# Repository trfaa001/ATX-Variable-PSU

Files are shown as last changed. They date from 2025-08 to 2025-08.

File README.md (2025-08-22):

# ATX-Variable-PSU
DIY variable power supply using an ATX PSU and buck converter.

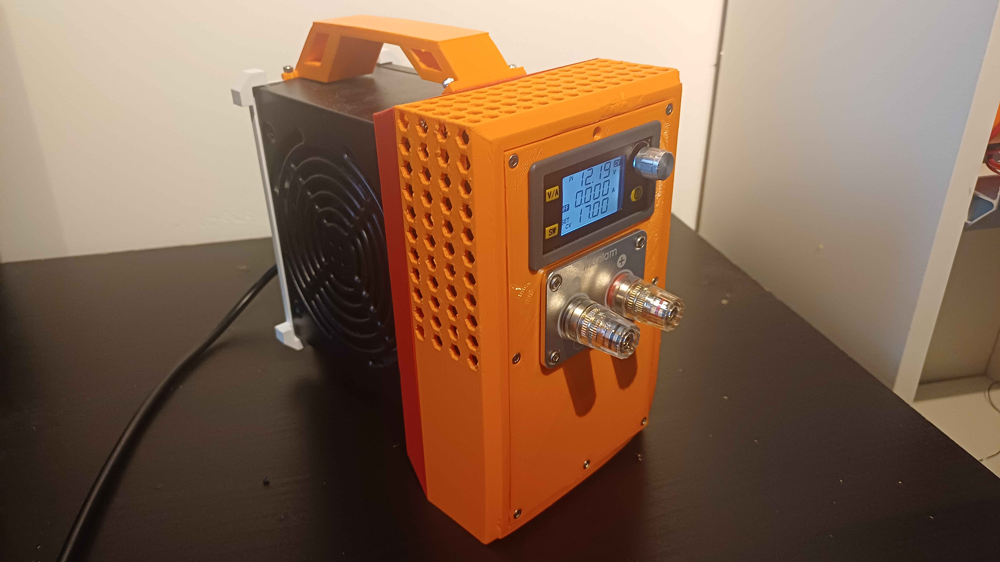
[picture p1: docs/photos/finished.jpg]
Project Image


## Features
---

* Voltage: 0-50V
* Amperage: 8A
* Repurposing ATX PSU
* Low-cost

## Parts list
---
| Qty | Component | Notes | Link |
|-----|---|---|---|
| 1 | ATX Power Supply | Corsair CV650 | [Product page](https://www.corsair.com/us/en/p/psu/cp-9020211-na/cv-series-cv650-650-watt-80-plus-bronze-certified-psu-cp-9020211-na) |
| 1 | Buck Converter Module | XY5008E from Aliexpress | [Product page](https://www.aliexpress.com/item/1005005247897362.html) |
| 1 | Banana Plug Connectors | 1 red, 1 black | [Product page](https://www.aliexpress.com/item/1005006516519813.html) |
| 1 | XT90 Female Connector | High current output connector | [Product page](https://www.aliexpress.com/item/1005007620266465.html) |
| 1 | XT90 Male Plug | High current plug | [Product page](https://www.aliexpress.com/item/1005008308472728.html) |
| 1 | 4mm Banana plug to alligator clip | Standard test leads | [Product page](https://www.aliexpress.com/item/1005006537881871.html) |
| 1 | Enclosure | 3D printed (see Fusion file) | [Mechanical (Fusion 360 + STL)](mechanical/) |
| 1 | PCB | Connecting the ATX 12V to a single line | [PCB design (Kicad + exports)](hardware/kicad/) |
| ~30 | Screws M3x10 mm | Connecting the parts togheter | [Product page](https://www.aliexpress.com/item/32836902463.html) |
| — | Wires, Heat Shrink, etc. | For connections | — |

## Recommended 3d print settings
---
| Setting | Value | Notes |
|---|---|---|
| Layer Height | maximum 0.22 mm | Standard balance of speed/quality |
| Infill | minimum 10% | Higher infill for more strength |
| Perimeters | 2-3 | Improves wall strength |
| Material | PLA or PETG | PETG for heat resistance |
| Supports | everywhere | Depends on model orientation |
| Bed Adhesion | Brim | If warping occurs |

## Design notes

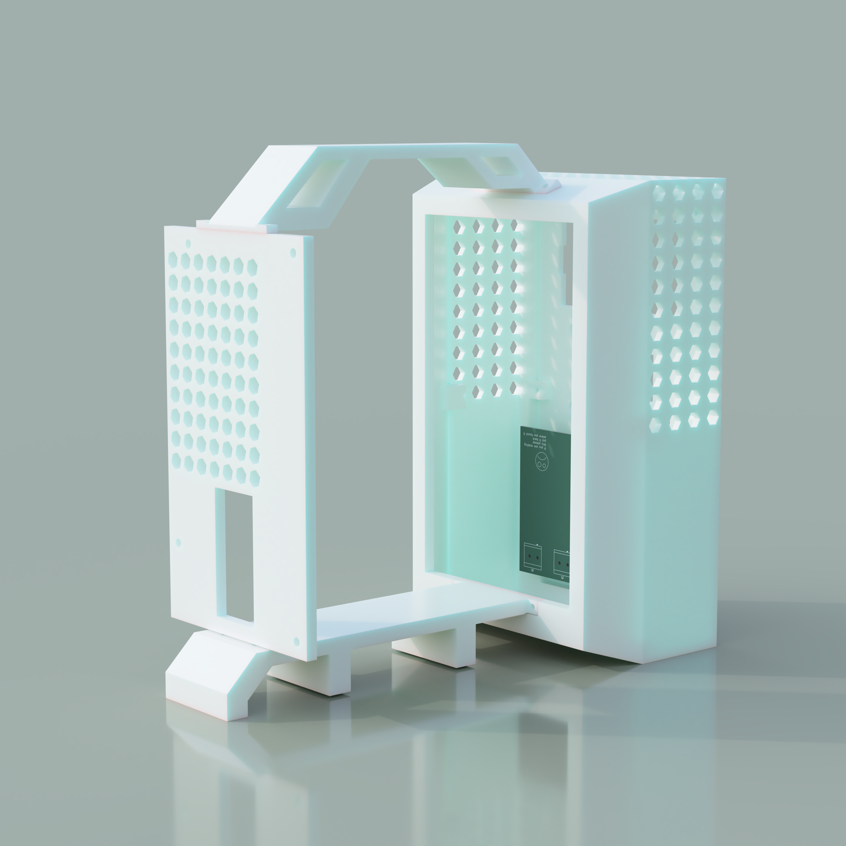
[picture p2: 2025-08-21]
mechanical/photos/Variable PSU back.png

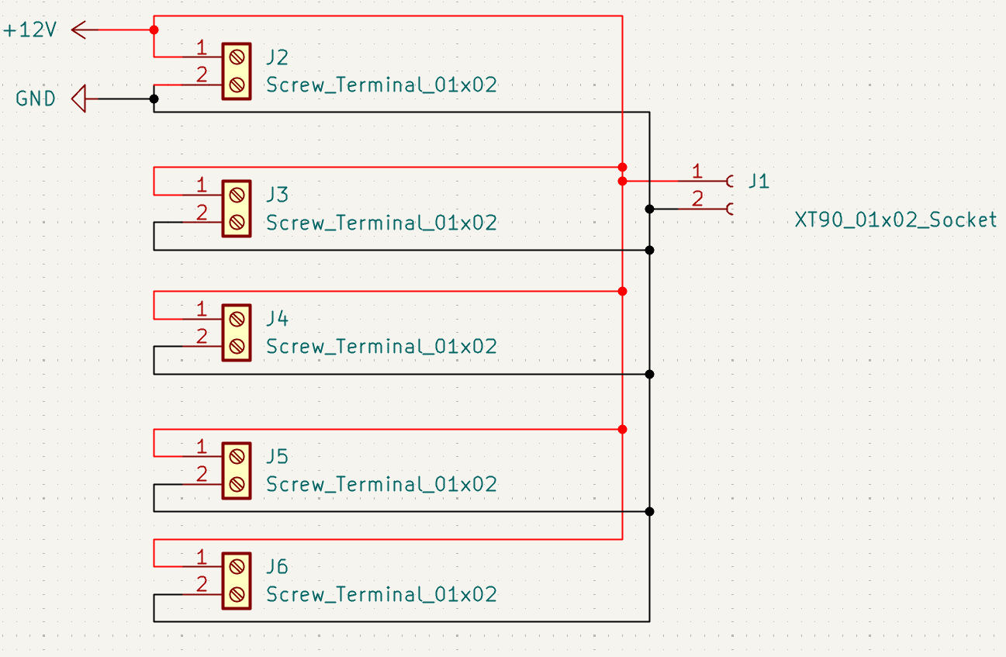
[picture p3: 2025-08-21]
hardware/kicad/photos/schematic.png

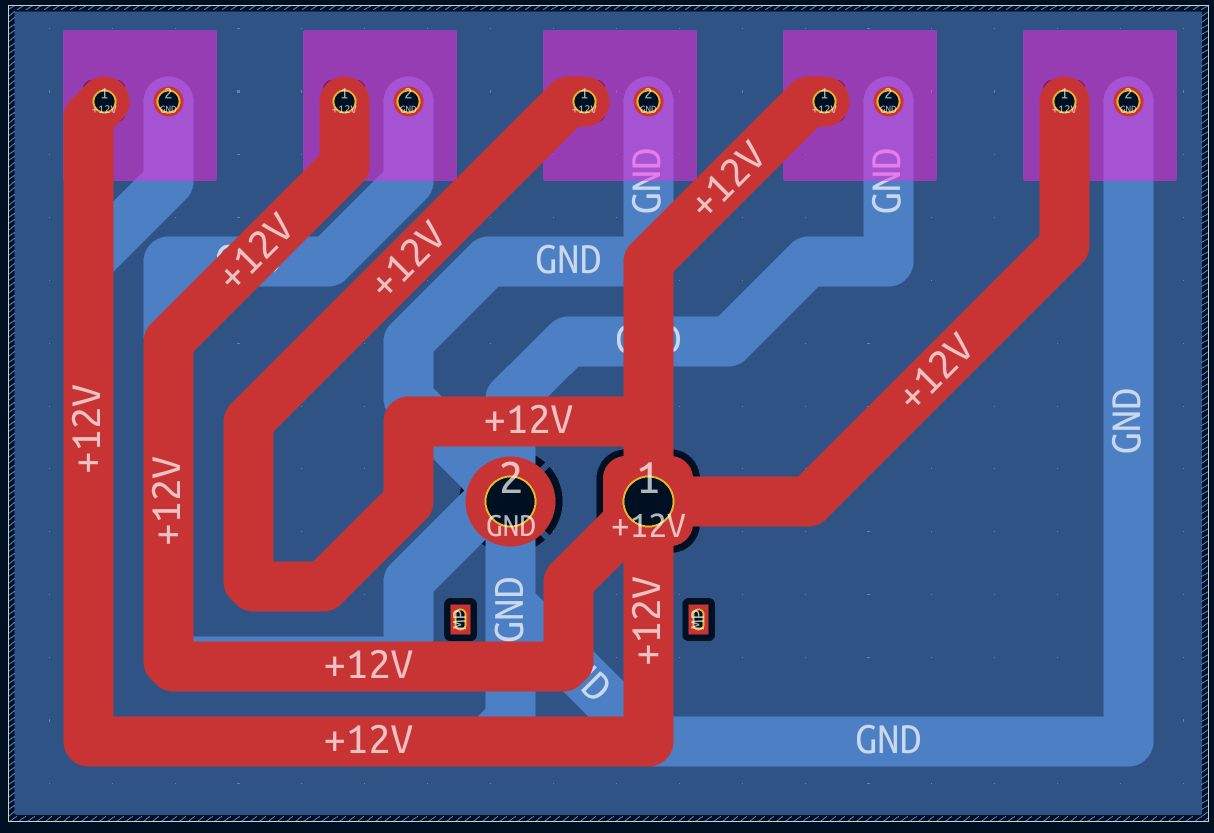
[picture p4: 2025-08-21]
hardware/kicad/photos/pcb.png

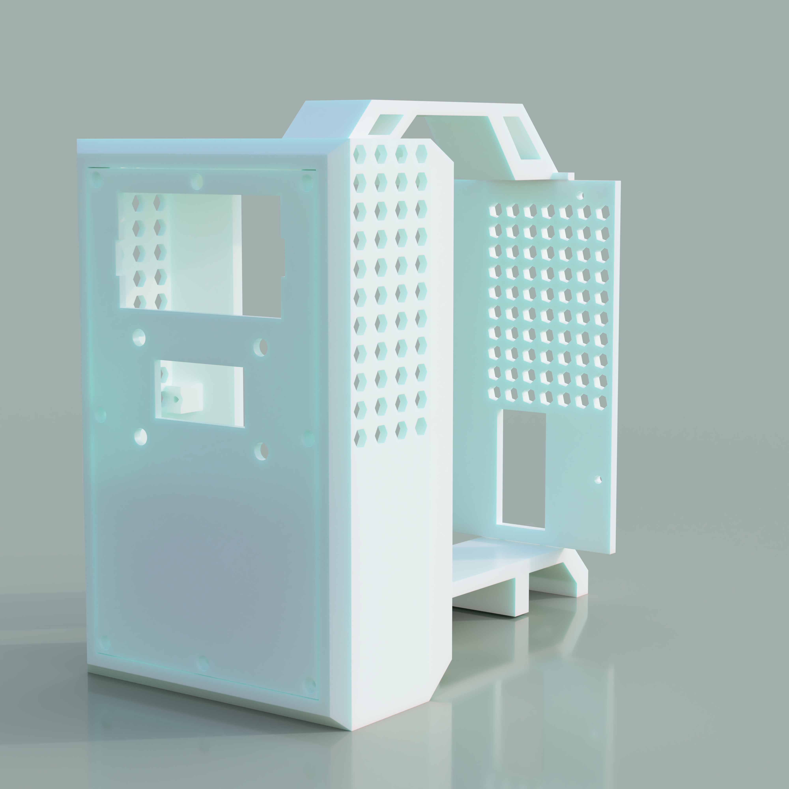
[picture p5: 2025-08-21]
mechanical/photos/Variable PSU front.png

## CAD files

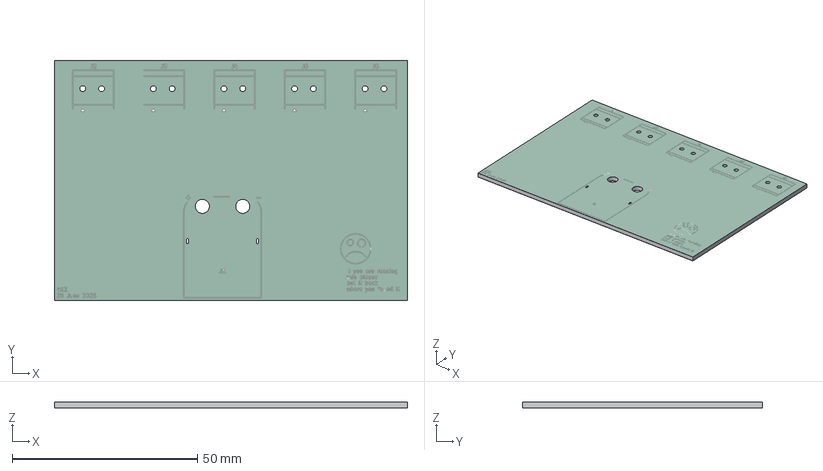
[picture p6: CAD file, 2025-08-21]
hardware/kicad/exports/PSU to buck.step
95.2 x 64.8 x 1.66 mm
PSU to buck_silkscreen
PSU to buck_soldermask
PSU to buck_PCB

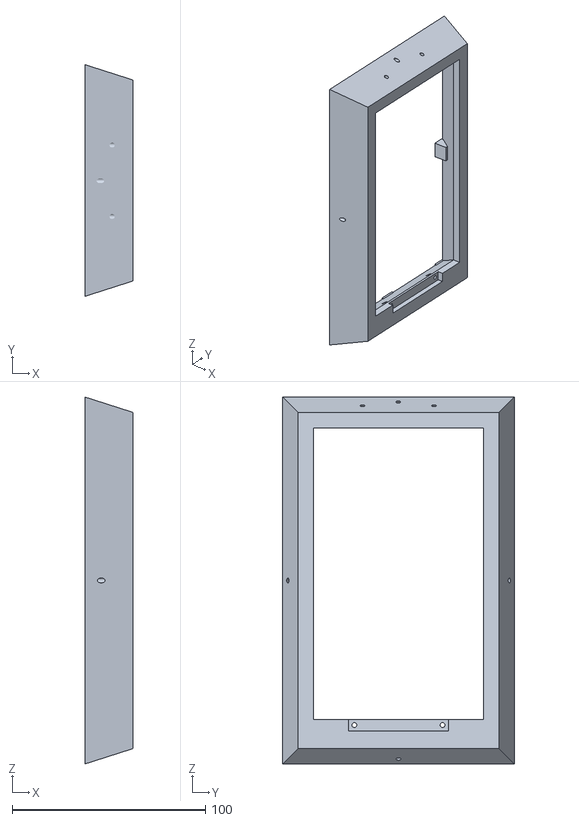
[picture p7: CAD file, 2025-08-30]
mechanical/3D print STLs/Back.stl
25.0 x 120.0 x 190.0

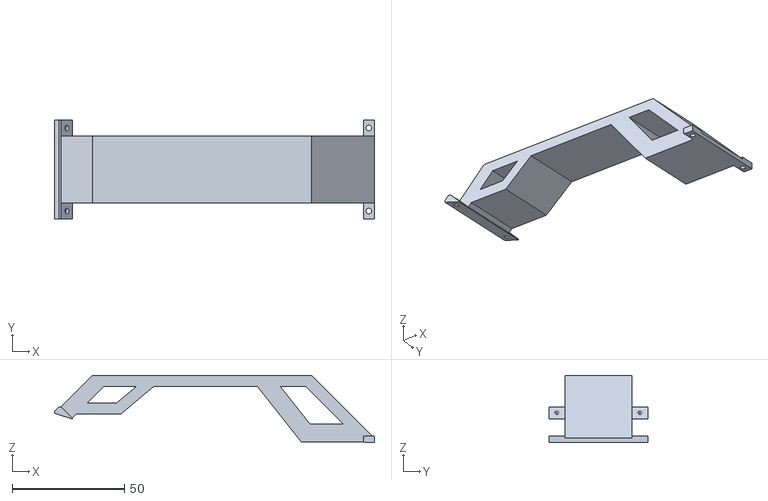
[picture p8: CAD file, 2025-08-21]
mechanical/3D print STLs/Handle.stl
142.5 x 44.0 x 30.0

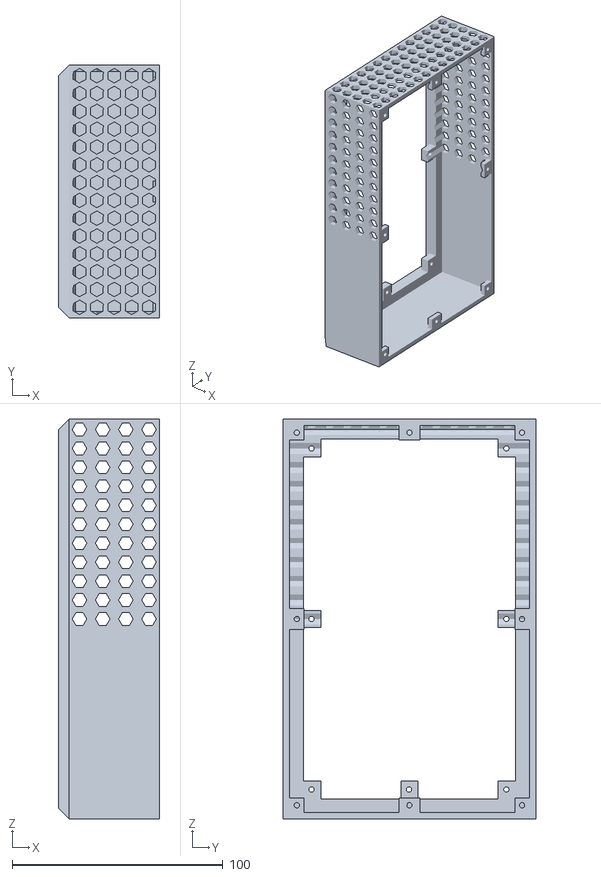
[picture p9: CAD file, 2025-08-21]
mechanical/3D print STLs/Front.stl
48.0 x 120.0 x 190.0

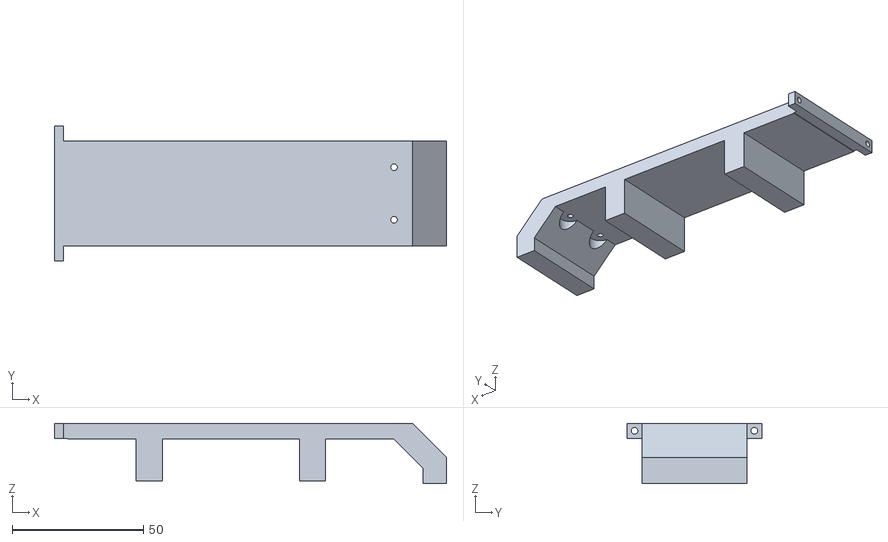
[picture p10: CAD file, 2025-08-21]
mechanical/3D print STLs/Bottom.stl
149.5 x 51.4 x 23.0

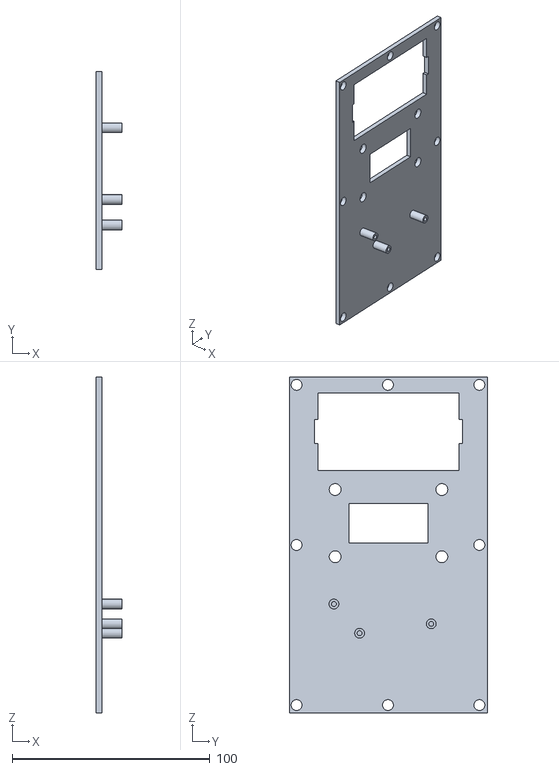
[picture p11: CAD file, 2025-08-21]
mechanical/3D print STLs/FrontPlate.stl
13.0 x 100.0 x 170.0

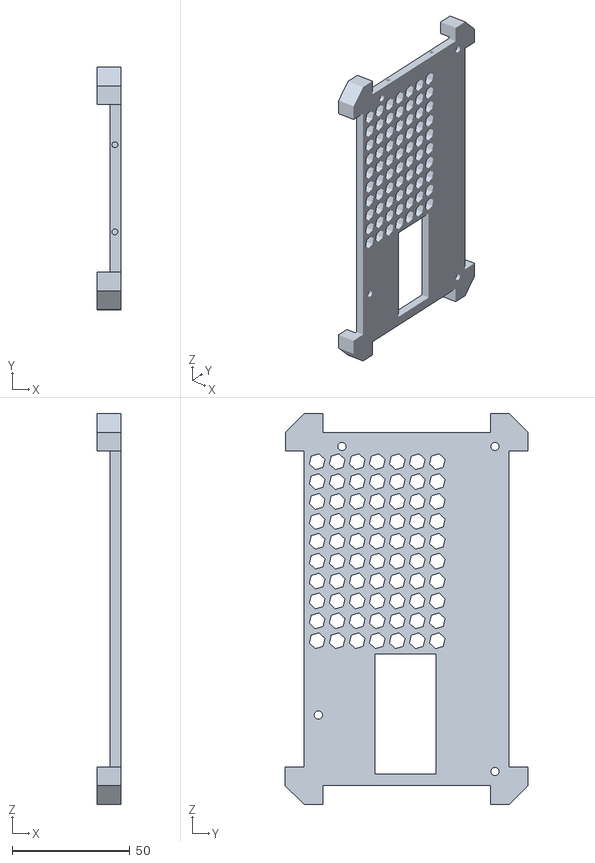
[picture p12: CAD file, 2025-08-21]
mechanical/3D print STLs/Backplate.stl
10.0 x 103.1 x 166.0

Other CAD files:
mechanical/Blender/assets/materials/geometric-patter_19b2c3d9-954c-4562-87f0-849a1d0f68e2/geometric-pattern-black-plastic_2K_b37b10a6-8506-4bd7-a7b7-56e2781c4085.blend
mechanical/Blender/assets/materials/glass_e6983950-eec4-448d-8f40-162ec1f72010/glass_2K_3b84c824-2fd2-46be-8f6c-2f605136b06c.blend
mechanical/Blender/assets/materials/printed-plastic_75caaa2c-9264-4a56-84e6-1f6d7c309a9f/printed-plastic_d4f76f48-5f4e-4c5e-8778-a90243d858fc.blend
mechanical/Blender/assets/materials/wood-125-dark_f5fbb285-b509-4c0a-8790-9032de19d130/wood-125-dark_2K_4256672c-1261-4907-8ccc-b29b9d68f0e2.blend
mechanical/Blender/assets/materials/wood-fine_2f5fa5d6-8e8b-44b6-83a3-5693113bceb0/wood-fine_2K_1b230e28-ee0b-4d49-b0b2-d2b8d28b4616.blend
mechanical/Blender/assets/materials/wood-parquet_8481c0f3-37d5-4608-925a-d41b187d8fd3/wood-parquet_2K_42cb15d6-d831-4864-89ea-fe33a834a8c5.blend
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

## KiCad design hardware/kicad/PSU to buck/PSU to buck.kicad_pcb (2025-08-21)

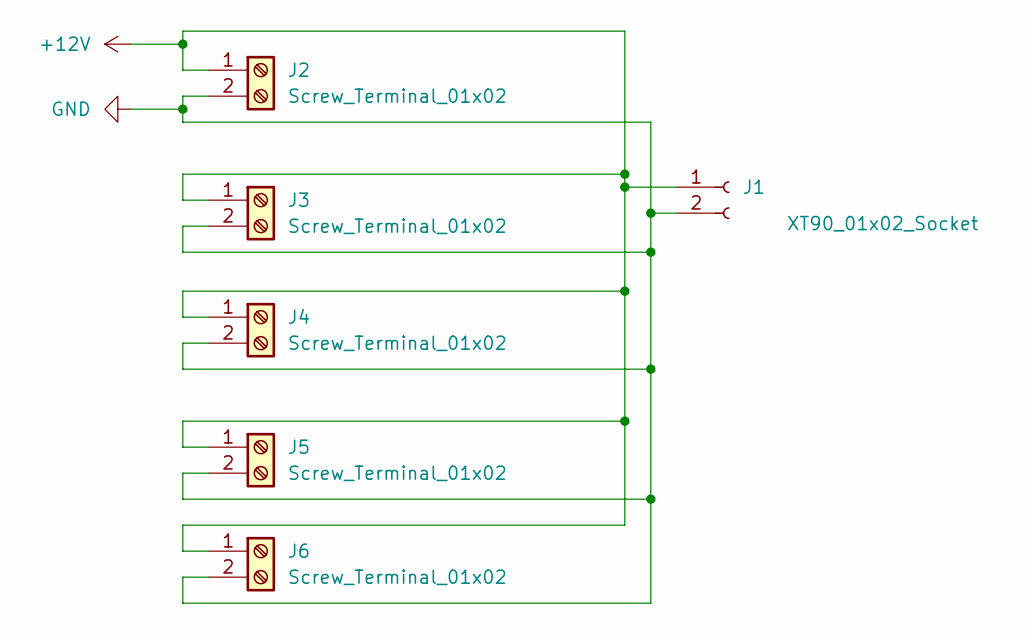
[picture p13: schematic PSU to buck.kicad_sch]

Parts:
J1: XT90_01x02_Socket; AMASS_XT90PW-M_1x02_P10.90mm_Horizontal
J2, J3, J4, J5, J6: Screw_Terminal_01x02; TerminalBlock_CUI_TB007-508-02_1x02_P5.08mm_Horizontal

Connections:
+12V: J1.1, J2.1, J3.1, J4.1, J5.1, J6.1
GND: J1.2, J2.2, J3.2, J4.2, J5.2, J6.2

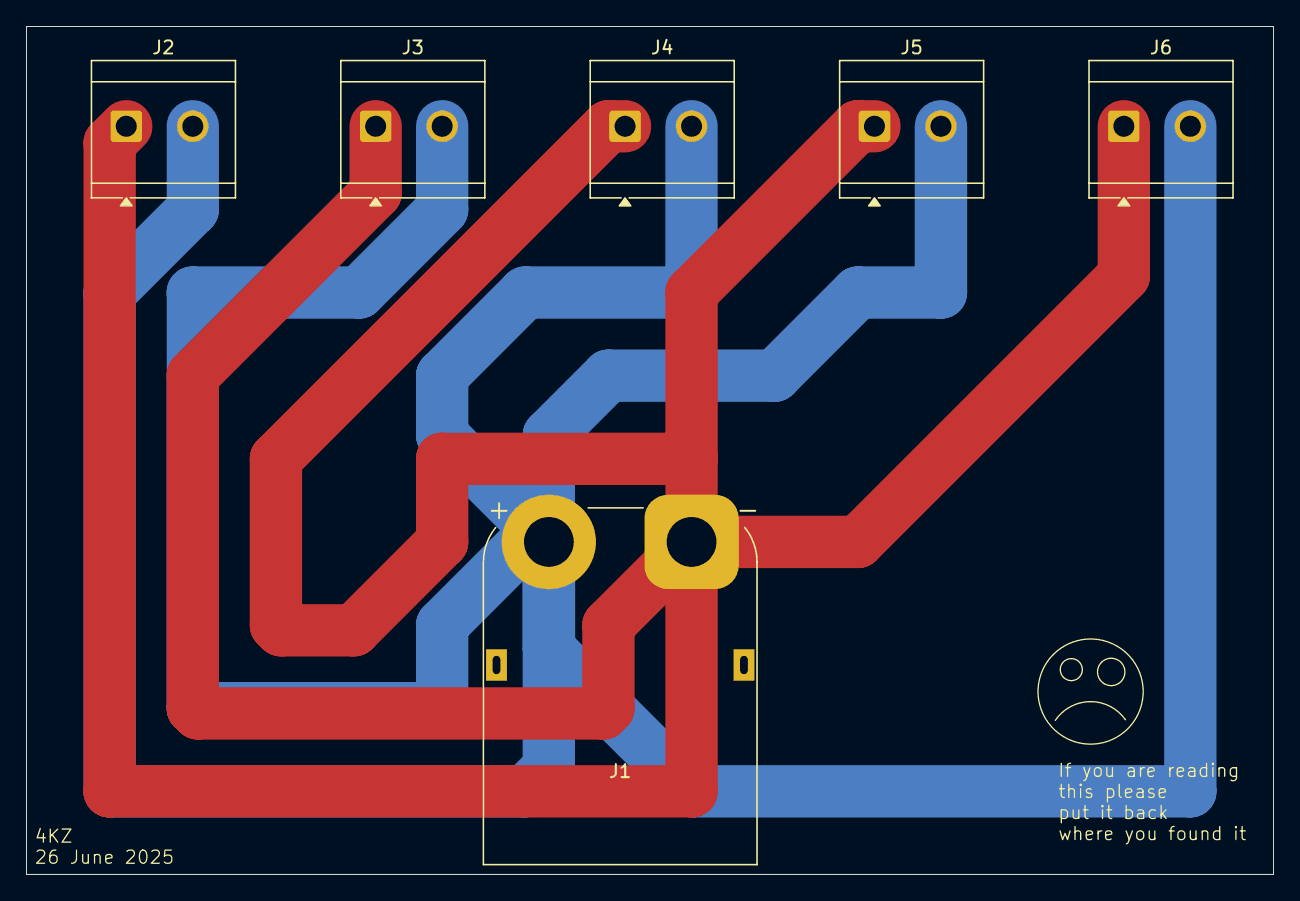
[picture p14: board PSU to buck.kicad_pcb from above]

Board: 2 copper layers, 95.2 x 64.8 mm, 6 parts (0 on the bottom side), 2 nets.

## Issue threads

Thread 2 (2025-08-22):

Difficult to screw in the screws on the front part

trfaa001, 2025-08-22:
It is not possible to screw in the screws that connect the front part and back part, because there isn't enough clearance to use a screwdriver. And while one could use an allen key, it doesn't provide enough force on the screw to drive it trough the screw hole with the current dimensions.

Closed 2025-08-30.

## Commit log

2025-08-21 Initial
    First commit. Added files laying around.
    [Back.stl, Backplate.stl, Bottom.stl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]
2025-08-22 Add KiCad PCB exports and update README
    Added generated drill, footprint, and Gerber files for the 'PSU to buck' PCB. Updated the project output paths in the KiCad project file. The README was updated to include PCB and 3D print settings. 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
    [PSU to buck-B_Cu.gbr, PSU to buck-B_Mask.gbr, PSU to buck-B_Paste.gbr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]
2025-08-22 Update screw quantity and product link in README
    Changed the quantity of M3x10 mm screws from 1 to approximately 30 and updated the product link to a more relevant source in the parts list.
2025-08-30 Angled screw holes between front and back part
    This change fixes the issue where the screws couldnt be fully screwed in because of the lack of clearance.
    [Back.stl, geometric-pattern-black-plastic_2K_b37b10a6-8506-4bd7-a7b7-56e2781c4085.blend, glass_2K_3b84c824-2fd2-46be-8f6c-2f605136b06c.blend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]
